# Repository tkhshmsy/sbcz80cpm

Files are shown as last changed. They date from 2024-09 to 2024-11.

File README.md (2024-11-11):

# sbcz80cpm
Single Board Computer with Z80 for CP/M

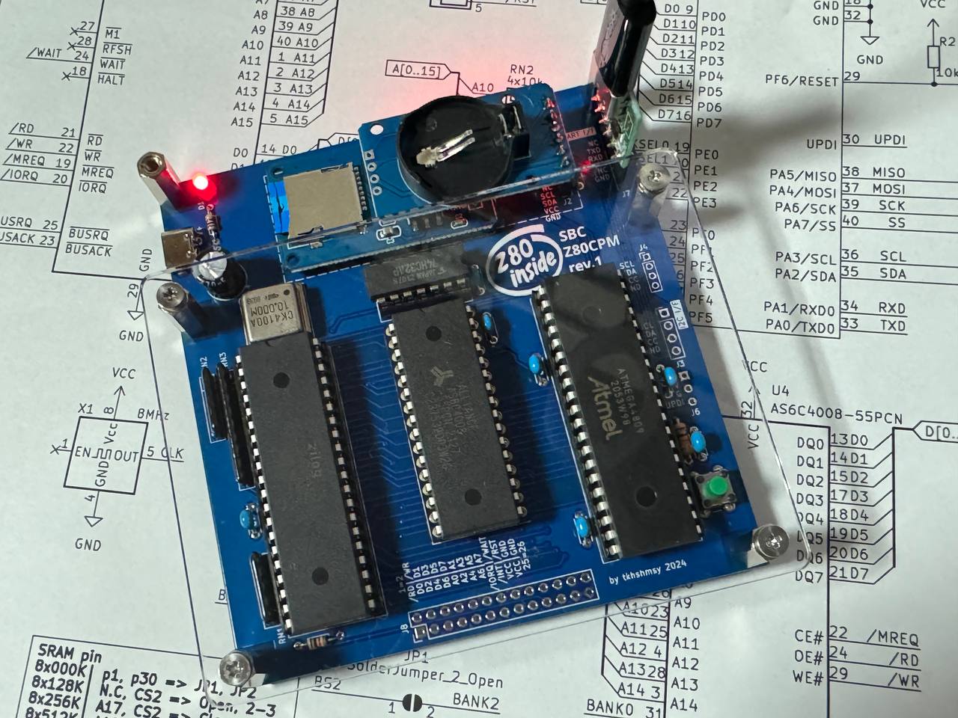
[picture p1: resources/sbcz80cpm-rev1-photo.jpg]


# Features
* Z80 cpu board for CP/M, without any ROM chips
  * supports 128KB to 512KB of SRAM, banked in 32KB
* ATMEGA4809 as I/O Engine sub system
  * Boot loader control
  * UART for console Input/Output
  * Floppy Disk Emulation with SD Card via SPI
  * RTC via I2C
  * other I2C devices

# PCB
## Schematics and Layout
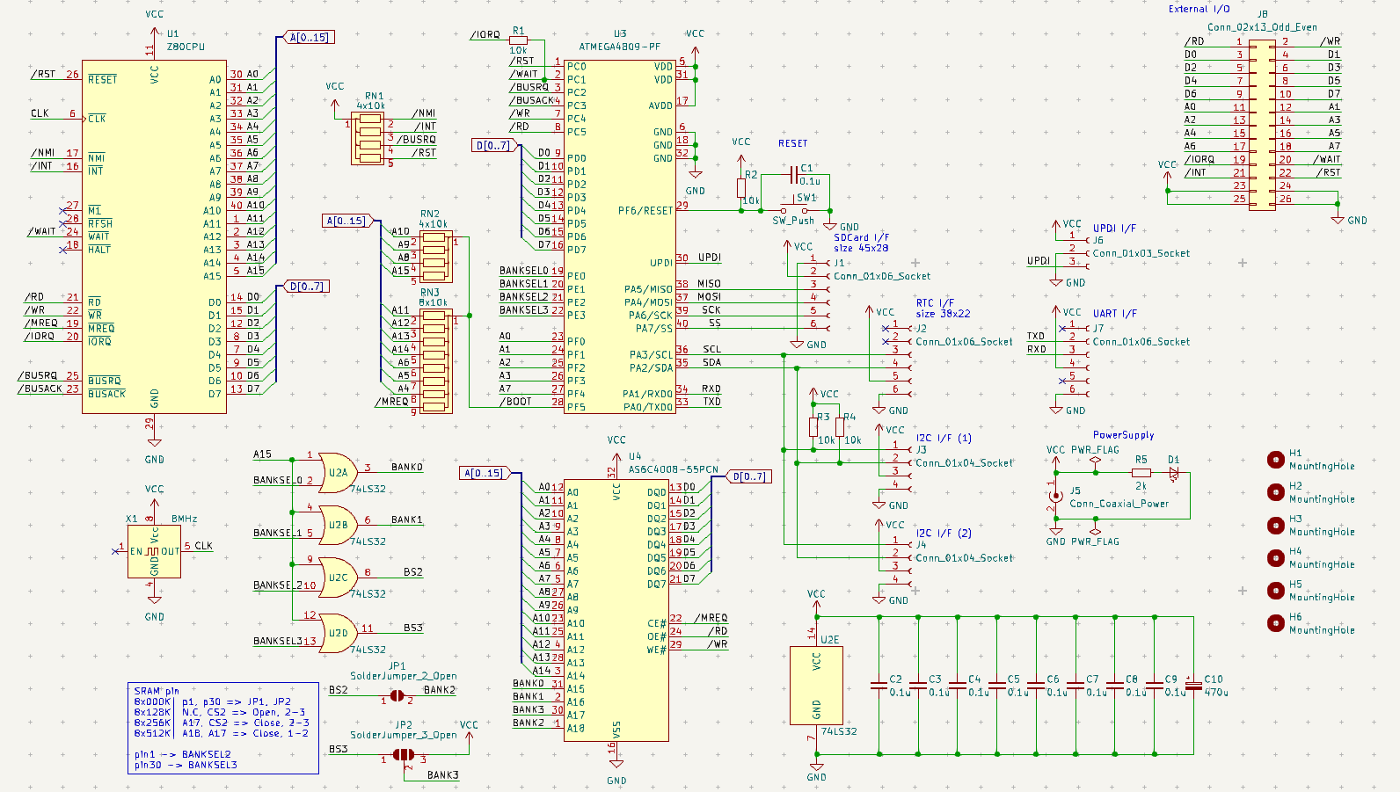
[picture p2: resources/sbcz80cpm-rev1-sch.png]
sch

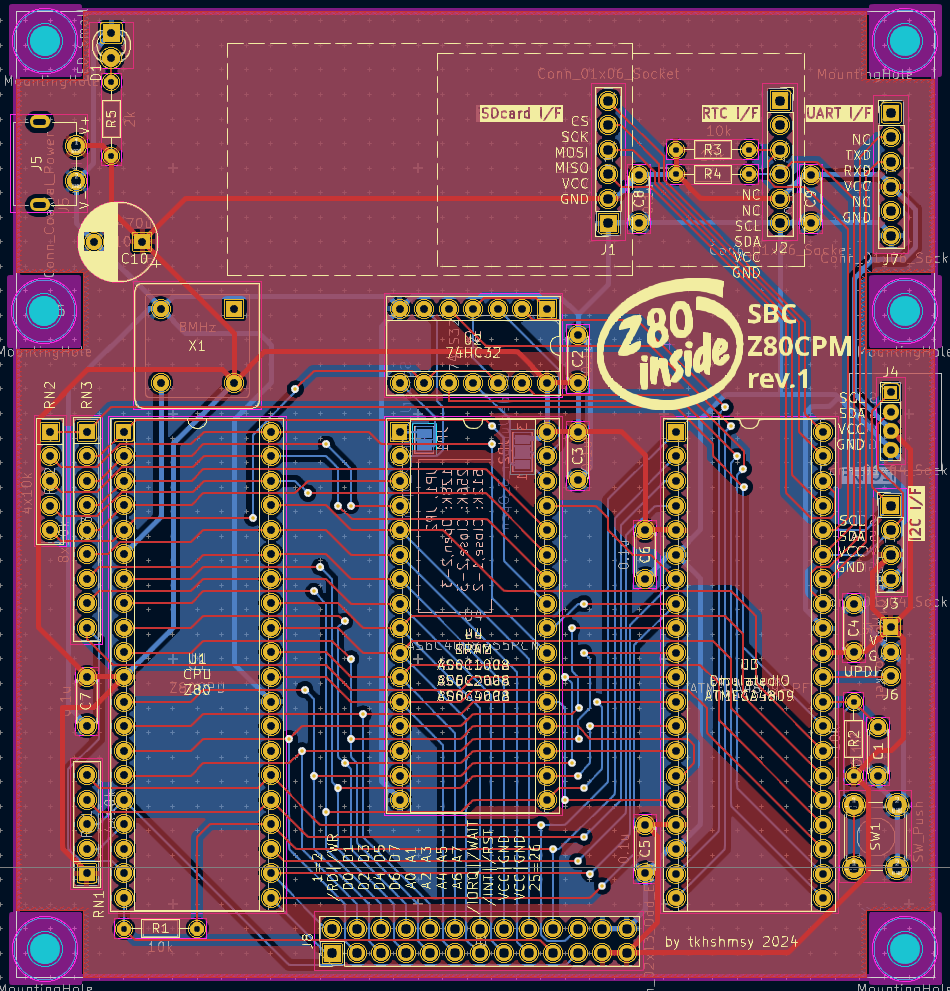
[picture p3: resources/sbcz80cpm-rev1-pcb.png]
pcb


## BOM
| Ref | Name | Qty | Description | Package | Link |
| --- | ---- | --- | --- | --- | ---- |
| U1 | Z80 | 1 | Z80 CPU | DIP40 | Zilog Z84C00*, NEC uPD780C |
| U2 | 74HC32 | 1 | Quad OR | DIP14 | [akizuki](https://akizukidenshi.com/catalog/g/g112877/)|
| U3 | ATMEGA4809 | 1 | ATMEGA4809 | PDIP40 | [akizuki](https://akizukidenshi.com/catalog/g/g116144/)|
| U4 | AS6C4008 | 1 | SRAM | DIP32 | [mouser](https://www.mouser.jp/ProductDetail/Alliance-Memory/AS6C4008-55PCN?qs=E5c5%252Bmu3i3%252BMOyro1Tlhzg%3D%3D)|
| X1 | 1-10MHz | 1 | Crystal OSC | DIP8 | [akizuki 8MHz](https://akizukidenshi.com/catalog/g/g117022/), [akizuki 10MHz](https://akizukidenshi.com/catalog/g/g117023/)|
| C1, C2, C3, C4, C5, C6, C7, C8, C9 | 0.1uF | 9 | | ||
| C10  | 470uF | 1 | | ||
| R1 | 1K-10K | 1 | for /WAIT control, 10K(-5MHz), 1K(8MHz-)| ||
| R2 | 10K | 1 | for pullup | ||
| R3, R4 | 10K | 2 | for I2C pullup | ||
| R5 | 1K | 1 | for LED | ||
| RN1 | 10Kx4 | 1 | for pullup | |[akizuki](https://akizukidenshi.com/catalog/g/g111909/)|
| RN2 | 10Kx4 | 1 | for IPL control | ||
| RN3 | 10Kx8 | 1 | for IPL control | |[akizuki](https://akizukidenshi.com/catalog/g/g111910/)|
| D1 | LED | 1 | 3mm | ||
| SW1 | Push Button | 1 | Reset SW| |[akizuki](https://akizukidenshi.com/catalog/g/g103647/)|
| J1, J2 | 1x6 Pin Socket | 2 | for SDCard, RTC | ||
| J3 | 1x4 Pin Socket | 1 | for I2C | pitch 2.54 ||
| J4 | 1x4 Pin Socket | 1 | for I2C | pitch 2.0 ||
| J5 | USB Type-C Power | 1 | for PowerSupply | |[akizuki](https://akizukidenshi.com/catalog/g/g116895/)|
| J6 | 1x3 Pin Socket | 1 | for UPDI | ||
| J7 | 1x6 Pin Header | 1 | for Serial comm | ||
| J8 | 2x13 Pin Header | 1 | for I/O Bus export | ||
| SDCard I/F | SD Card Module | 1 | | |[amazon.co.jp](https://www.amazon.co.jp/dp/B083DT3LQK)|
| RTC I/F | RTC Module | 1 | | |[amazon.co.jp](https://www.amazon.co.jp/dp/B081RJRB8N)|

## Memory Map

### System Memory
| Address | Size | Name | Note |
| ----- | ---- | ---- | ---- |
|0x0000 - 0x7FFF| 32KB | RAM | Banked memory selected with BANKSEL0-3 |
|0x8000 - 0xFFFF| 32KB | RAM | Fixed to "the tail of Banks" |

### SRAM Banks
* every 32KB, selected with BANKSEL0-3
  * Bank0 : 0x0000 - 0x7FFF
  * ...
* "the tail of Banks" which is mapped into 0x8000 - 0xFFFF on system
  * 128KB: 0x18000 - 0x1FFFF
  * 256KB: 0x28000 - 0x2FFFF
  * 512KB: 0x48000 - 0x4FFFF

# License
* MIT
  * contains follows
    * schematics and PCB
    * firmware `I/O Engine`
    * boot loaders and customized bios
  * the others are NOT included.

# Author
* [tkhshmsy@gmail.com](tkhshmsy@gmail.com)

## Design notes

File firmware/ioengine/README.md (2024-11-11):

# I/O Engine for sbcz80cpm

the I/O device for sbcz80cpm powered by [ATMEGA4809](https://www.microchip.com/en-us/product/atmega4809).

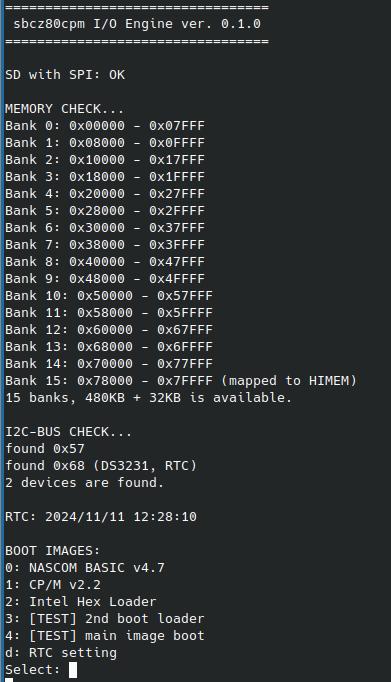
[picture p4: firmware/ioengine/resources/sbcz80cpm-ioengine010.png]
I/O Engine


## Features
* Boot control
  * provides IPL for no ROM / full RAM system
* I/O control, mostly for CP/M
  * Console I/O which is connected to host via UART
  * Disk I/O
  * RTC
  * communicate with I2C devices

## Requirements
* [platformio](https://platformio.org/)
  * cross development platform for embedded systems
* [pymcuprog](https://github.com/microchip-pic-avr-tools/pymcuprog)
  * serial to UPDI programmer for AVR

## Build
use platformio.
* modify `platformio.ini` if it needs

```bash
## only once, write the fuse to enable H/W RESET.
$ pio run -t fuses

## compile
$ pio run

## compile and upload
$ pio run -t upload
```

References,
* [PlatformIO Community/Hardware reset on AVR 4809](https://community.platformio.org/t/hardware-reset-on-avr-4809/24219)

## Design

### Connections
* for devices
  * UART
    * for host communication, 115200bps 8N1
  * I2C
    * RTC
    * other i2c devices
  * SPI
    * SD card, formatted VFAT/FAT32 
* for _Z80_
  * /WAIT, /IOREQ
  * /WR
  * /RD
  * AddressBus
  * DataBus
  * /MREQ

### Boot sequence and IPL
_sbcz80cpm_ is all RAM system, and has no ROM. Therefore, the IPL should be written into RAM by any way.
For this, at booting, _I/O Engine_ turns _Z80_ into bus master and writes IPL to the top of RAM.
However, as the _I/O Engine_(ATMEGA4809) has not enough I/O ports for address bus, the IPL needs to execute within a limited address space.

1. reset _Z80_
2. Loading _IPL_ (`/boot1st.bin`)
   1. assert /BUSREQ = 0
   2. wait until /BUSACK = 0 to enter BusMaster
   3. assert /BOOT = 0
      1. A15-8,A6-4 is 0
      2. /MREQ is 0 (SRAM is activated)
   4. assert A7 = 0
   5. using /WR, A0-3, write IPL from 0x0000 to 0x000F
   6. release /BOOT = 1
   7. release /BUSREQ = 1 to leave BusMaster
3. reset _Z80_, start _IPL_ from 0x0000
4. (_I/O Engine_ starts main loop)
5. _IPL_ (`/boot1st.bin`) is executed
   1. write 0x02 to I/O port 0x8F to prepare the binary of '2nd boot loader'
   2. read 256 times from I/O port 0x8F
      1. I/O Engine returns binary of _2nd boot loader_
   3. write each bytes from 0xFF00 to 0xFFFF.
   4. jump to 0xFF00
6. _2nd boot loader_ (e.g. `/boot2nd.bin`) is executed
   1. write 0x03 to I/O port 0x8F to prepare the binary of 'main image'
   2. read 32768 times from I/O port 0x8F
      1. I/O Engine returns binary of _main image_
   3. write each bytes from 0x0000 to 0x7FFF.
   4. jump to 0x0000

At here, the _IPL_ (boot1st.bin) has to be less than 16 bytes of code. Which is quite possible with the extra instructions of _Z80_.
Similarly, the _2nd Boot Loader_ has also to be less than 256 bytes of code, but for the _Z80_, 256 bytes is enough space to perform various operations.

### I/O sequence
The _I/O Engine_ needs to respond to IN/OUT instructions of _Z80_.
However, even though the _I/O Engine_ is running at 20MHz, it is still too slow to respond to the _Z80_ without WAIT.

So, it is solved this in the same way as other similar projects (e.g. [Z80MBC2](https://github.com/SuperFabius/Z80-MBC2), [Z80MBC3](https://github.com/eprive/Z80-MBC3)).

1. _I/O Engine_ waits until /WAIT = 0
   1. _Z80_ executes the instruction 'OUT'or 'IN', so assert /IOREQ = 0
   2. because /IOREQ connected to /WAIT with resistor, it turns /WAIT = 0
   3. IN/OUT command-cycle is 'T1, T2, TW, T3', _Z80_ waits until /WAIT =1.
      1. refer to [Z80 CPU User Manual](https://www.zilog.com/docs/z80/um0080.pdf) page 11
      2. in TW cycle, /RD,/WR, Address and Data is already asserted.
2. _I/O Engine_ reads /WR, /RD, Address and Data buses to execute it's API.
   1. /WR = 0 is asserted, it is a 'write' operation. _I/O Engine_ reads from Data bus.
   2. /RD = 0 is asserted, it is a 'read' operation. _I/O Engine_ changes Data bus to output, and outputs the data.
3. _I/O Engine_ releases bus,
   1. asserts /BUSREQ = 0
   2. asserts /WAIT = 1 as output port (at here, still /IOREQ = 0 yet)
      1. _Z80_ start to continues executing the T3 cycle and the next instruction.
      2. But because /BUSREQ = 0, _Z80_ waits at the head of T1 in M1 cycle of the next instruction.
         1.  refer to [Z80 CPU User Manual](https://www.zilog.com/docs/z80/um0080.pdf) page 12
         2. _Z80_ does not touch its buses yet and waits until /BUSACK = 0.
   3. release Data bus = High-Z as input port if the case that _I/O Engine_ was output any data.
   4. release /WAIT = High-Z as input port.
   5. asserts /BUSREQ = 1 to release all buses and wake up _Z80_.
4. _Z80_ continues to next cycle...

## Boot configuration
At booting, _I/O Engine_ read `/boot.cfg` from SD card.
`boot.cfg` is written in the TSV (Tab Separated Value) format and contains the following items.

* (1) the title of the setting
  * e.g. `CP/M 2.2`
* (2) the full-path of 2nd boot loader. 
  * Normally `/boot2nd.bin` is used, but a modified one is able to use.
  * e.g. `/cpm22/cpm22ipl.bin`
* (3) the full-path of main image
  * e.g. `/cpm22/bios.bin`
* (4) the prefix of the disk-image-files
  * e.g. `/cpm22`

The _prefix_ in the 4th item is used for creating _the image-filename_ of _the floppy-disk-emulation_ and is expanded as follows:
* `prefix` + `/disk` + \<disk no.\> + `.img`

## API as I/O device
Mainly for CP/M, the _I/O Engine_ provides API centered around FloppyDisk emulation.
It is placed under 8-bit addresses as a _Z80_'s I/O device.

About floppy-disk emulation, the default setting is _ibm-3740 format_ as follows:
* tracks per disk: 77 (allows 0-76)
* sectors per track: 26 (allows 0-25)
* sector length: 128 bytes

### for READ
| Address | Function | Description |
|---|---|---|
| 0x80 | UARTST | return the status of UART |
| 0x81 | UART | receive from UART |
| 0x82 | SELDSK | return the number of current disk |
| 0x83 | SETTRK | return the number of current track |
| 0x84 | SETSEC | return the number of current sector |
| 0x85 | DISKIO | read the current sector, must to read sector length continuously |
| 0x86 | ---- | Not Implemented yet |
| 0x87 | ---- | Not Implemented yet |
| 0x88 | ---- | Not Implemented yet |
| 0x89 | (UPTIME) | Not Implemented yet |
| 0x8A | RTC | read RTC |
| 0x8B | I2CTRANS | return the result of transmit() of i2c |
| 0x8C | I2CREQ | return the result of available() of i2c |
| 0x8D | I2CDATA  | read from i2c |
| 0x8E | BANK | return the current bank of SRAM |
| 0x8F | MISC | return the binary data for IPL |

#### UARTST
| bit | Description |
|-----|---|
| 7-2 | Not used |
| 1 | Tx condition, 1: able to transmit, 0: busy |
| 0 | Rx condition, 1: able to receive, 0: no char |

### for WRITE
| Address | Function | Description |
|---|---|---|
| 0x80 | UARTST | No response |
| 0x81 | UART | transmit to UART |
| 0x82 | SELDSK | select the current disk |
| 0x83 | SETTRK | set the current track |
| 0x84 | SETSEC | set the current sector |
| 0x85 | DISKIO | write the current sector, must to write sector length continuously |
| 0x86 | ---- | Not Implemented yet |
| 0x87 | ---- | Not Implemented yet |
| 0x88 | ---- | Not Implemented yet |
| 0x89 | (UPTIME) | Not Implemented yet |
| 0x8A | RTC | write RTC |
| 0x8B | I2CTRANS | send transmit() to i2c |
| 0x8C | I2CREQ | send request() to i2c |
| 0x8D | I2CDATA  | write into i2c |
| 0x8E | BANK | set the current bank of SRAM |
| 0x8F | MISC | input |

#### MISC input
| value | description |
|---|---|
| 0x00  | set the dummy data 0x00 |
| 0x01  | set the binary of fixed _1st boot loader_ |
| 0x02  | set the binary of selected _2nd boot loader_ |
| 0x03  | set the binary of selected _main image_ |
| 0xFF  | reset _Z80_ |

## References
* Zilog
  * [Z80 CPU User Manual](https://www.zilog.com/docs/z80/um0080.pdf)
* Microchip ATMEGA4809
  * [ATMEGA4809](https://www.microchip.com/en-us/product/atmega4809)
  * [Datasheet](https://ww1.microchip.com/downloads/aemDocuments/documents/MCU08/ProductDocuments/DataSheets/ATmega4808-09-DataSheet-DS40002173C.pdf)
* Other Projects
  * [Z80MBC2](https://github.com/SuperFabius/Z80-MBC2)
  * [Z80MBC3](https://github.com/eprive/Z80-MBC3)

## License
* MIT

## Author
* [tkhshmsy@gmail.com](tkhshmsy@gmail.com)

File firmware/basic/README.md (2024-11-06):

# NASCOM BASIC v4.7b

forked from [Microsoft BASIC 4.7b](http://searle.x10host.com/z80/sbc_NascomBasic.zip) of Grant Searle's project.  

* BASIC interpreter for Z80
* BIOS.ASM is customized for sbcz80cpm
  * use UART for console Input/Output

```
Initializing sbcz80cpm...

Memory top? 
Z80 BASIC Ver 4.7b
Copyright (C) 1978 by Microsoft
56958 Bytes free
Ok

10 FOR I=0 TO 10
20 PRINT "Hello world!"
30 NEXT
run
Hello world!
Hello world!
Hello world!
Hello world!
Hello world!
Hello world!
Hello world!
Hello world!
Hello world!
Hello world!
Hello world!
Ok
```

## Requirements
* 'zasm' assembler
  * [zasm](https://k1.spdns.de/Develop/Projects/zasm/Distributions/)

## Build
* download 'basic.asm' from Grant's HomePage.
* execute 'make' command to get 'msbasic.bin'
```bash
/sbcz80cpm/firmware/basic$ ls
Makefile  README.md  basic.asm  init.asm

/sbcz80cpm/firmware/basic$ make
zasm -wuyb init.asm -o init.obj
assembled file: init.asm
    107 lines, 2 passes, 0.0015 sec.
    no errors

zasm -wuyb basic.asm -o basic.obj
assembled file: basic.asm
    4341 lines, 2 passes, 0.0261 sec.
    no errors

cat init.obj basic.obj > msbasic.bin

/sbcz80cpm/firmware/basic$ ls
Makefile  README.md  basic.asm  basic.lst  basic.obj  init.asm  init.lst  init.obj  msbasic.bin
```

### Setup

1. Copy `msbasic.bin` into `/basic` directory in SDcard.
2. Set up `/boot.cfg`
   1. set `/boot2nd.bin` as 2nd boot loader
      1. the general 2nd boot loader loads too many bytes, but it's safe.
   2. set `/basic/msbasic.bin` as main image
   3. set `/basic` as prefix to access disk images
      1. this is not neccessary, but recommended to avoid conflicts.
3. then, restart sbcz80cpm, and select above setting.

## References
* [Grant's homebuilt electronics](http://searle.x10host.com/)
  * [Grant's 7-chip Z80 computer](http://searle.x10host.com/z80/SimpleZ80.html)

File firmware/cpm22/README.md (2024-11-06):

# CP/M ver 2.2

62K CP/M ver 2.2 for sbcz80cpm

## Requirements
* 'zasm' assembler
  * [zasm](https://k1.spdns.de/Develop/Projects/zasm/Distributions/)
* 'cpmtools'
  * [Michael Haardt's cpmtools Main Page](http://www.moria.de/~michael/cpmtools/)
  * On Ubuntu, use `sudo apt install cpmtools`

## How to build
### BIOS and IPL
* bios.asm (bios.bin)
  * 62K CP/M ver 2.2 BIOS for sbcz80cpm
    * allocated at 0xF200
  * BOOT and WBOOT as CP/M API, loads system binary from 'disk0.img'
* cpm22ipl.asm (cpm22ipl.bin)
  * 2nd boot loader for sbcz80cpm
  * loads BIOS into 0xF200 and jump to 0xF200

```bash
/sbcz80cpm/firmware/cpm22$ ls
Makefile  README.md  bios.asm  cpm22ipl.asm

/sbcz80cpm/firmware/cpm22$ make
rm -f bios.bin cpm22ipl.bin *.lst *.hex
zasm -wuyb bios.asm -o bios.bin
assembled file: bios.asm
    368 lines, 2 passes, 0.0029 sec.
    no errors

zasm -wuyb cpm22ipl.asm -o cpm22ipl.bin
assembled file: cpm22ipl.asm
    57 lines, 2 passes, 0.0010 sec.
    no errors

/sbcz80cpm/firmware/cpm22$ ls
Makefile  README.md  bios.asm  bios.bin  bios.lst  cpm22ipl.asm  cpm22ipl.bin  cpm22ipl.lst
```
## How to set up system

### Get the system binary

1. Download OPERATING SYSTEMS binary from '[Unofficial CP/M Web site](http://www.cpm.z80.de/)'.
   * [CP/M 2.2 BINARY](http://www.cpm.z80.de/download/cpm22-b.zip)
2. Unpack to get the binary file 'CPM.SYS'.
   * 'CPM.SYS' includes CCP, BDOS, BIOS for 62K CP/M on Xerox1800 system.
3. Not using the BIOS for Xerox1800, so remove it and make CCP and BDOS binary.
   * `dd if=CPM.SYS of=ccpbdos.bin bs=128 count=44`
4. Make the system disk image at following step.

### Make the disk images

`bios.asm` is the 62K CP/M ver 2.2 BIOS for sbcz80cpm,
* supports _ibm-3740_ formatted disk image.
* supports 4 disks mounted.
  * `disk0.img`: system disk, must to install CCP and BDOS into boot track.
  * `disk1.img`: user disk (no needs the boot track)
  * `disk2.img`: user disk
  * `disk3.img`: user disk

> [!NOTE]
> ibm-3740 formatted disk image.
> * 77 tracks per disk
> * 26 sectors per track
> * 128 bytes per sector
> * 2 reserved tracks for system
> * skew factor is 6
> * Total: 256,256 bytes per disk

```bash
## System disk
### make empty disk image file (size = 128 * 26 * 77)
$ dd if=/dev/zero of=disk0.img bs=3328 count=77
### mkfs.cpm with ibm-3740 format and install the system binary into boot track
$ mkfs.cpm -f ibm-3740 -b ccpbdos.bin -L system disk0.img

## User disk (e.g. disk1.img)
$ dd if=/dev/zero of=disk1.img bs=3328 count=77
$ mkfs.cpm -f ibm-3740 disk1.img
```

To boot up CP/M, no files are needed but only the BIOS and the system binary in boot track.

### Control disk images
Using any other commands and files on CP/M, use cpmtools to deploy into disk images.

```bash
## list files in disk0.img
$ cpmls -f ibm-3740 disk0.img
## copy local file 'file.bin' into disk0.img (user 0)
$ cpmcp -f ibm-3740 disk0.img ./file.bin 0:
## copy file '0:file.bin' from disk0.img to local
$ cpmcp -f ibm-3740 disk0.img 0:file.bin ./
## remove '0:file.bin' from disk0.img
$ cpmrm -f ibm-3740 disk0.img 0:file.bin
```

> [!NOTE]
> _ibm-3740_ is the default format of cpmtools.
> so, `-f ibm-3740` option is able to be omitted.

### Setup sbcz80cpm

1. Copy `bios.bin` and `cpm22ipl.bin` into `/cpm22` directory in SDcard.
2. Copy disk images into `/cpm22` directory in SDcard.
3. Set up `/boot.cfg`
   1. set `/cpm22/cpm22ipl.bin` as 2nd boot loader
   2. set `/cpm22/bios.bin` as main image
   3. set `/cpm22` as prefix to access disk images
4. then, restart sbcz80cpm, and select above setting.

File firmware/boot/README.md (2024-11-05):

# Boot loaders for sbcz80cpm

## Contents
* Makefile
  * Makefile for all
* README.md
  * this document
* boot1st.asm
  * IPL for sbcz80cpm
    * load selected '2nd boot loader' into 0xff00, and jump to
* boot2nd.asm
  * general 2nd boot loader
    * load 32KB into 0x0000
* bootihex.asm
  * intel hex loader
    * load intel-hex formatted file
      * recommended to use 'slowtransfer.sh' because of no flow control.
    * after loaded, input 'StartAddress' to jump to
* slowtransfer.sh
  * script for 'slow' transfer
    * usage: `./slowtransfer.sh <device> <filename>`
    * send each bytes with interval
* test2nd.asm
  * test code of 2nd boot loader
    * output message and HALT
* testimg.asm
  * test code of main image
    * output message and HALT

## Requirements
* 'zasm' assembler
  * [zasm](https://k1.spdns.de/Develop/Projects/zasm/Distributions/)

## Build
* execute 'make' command

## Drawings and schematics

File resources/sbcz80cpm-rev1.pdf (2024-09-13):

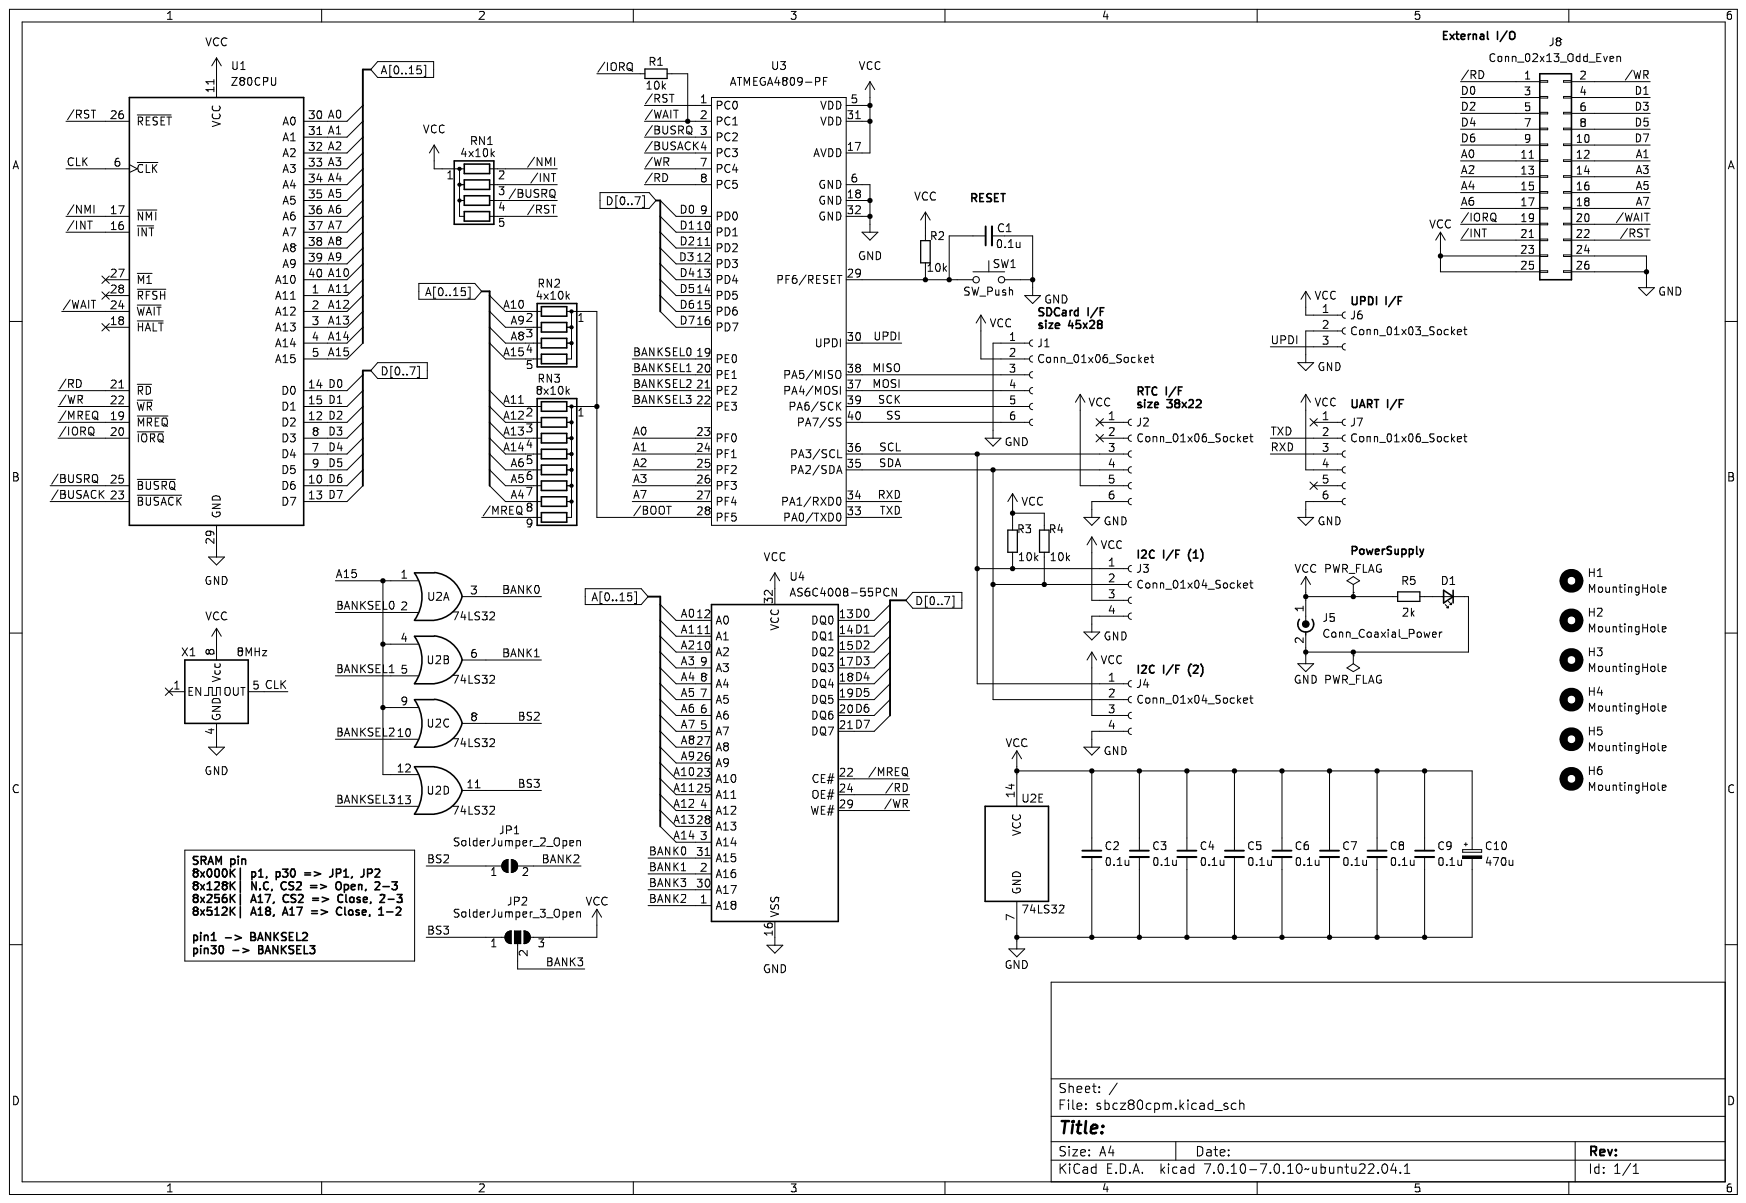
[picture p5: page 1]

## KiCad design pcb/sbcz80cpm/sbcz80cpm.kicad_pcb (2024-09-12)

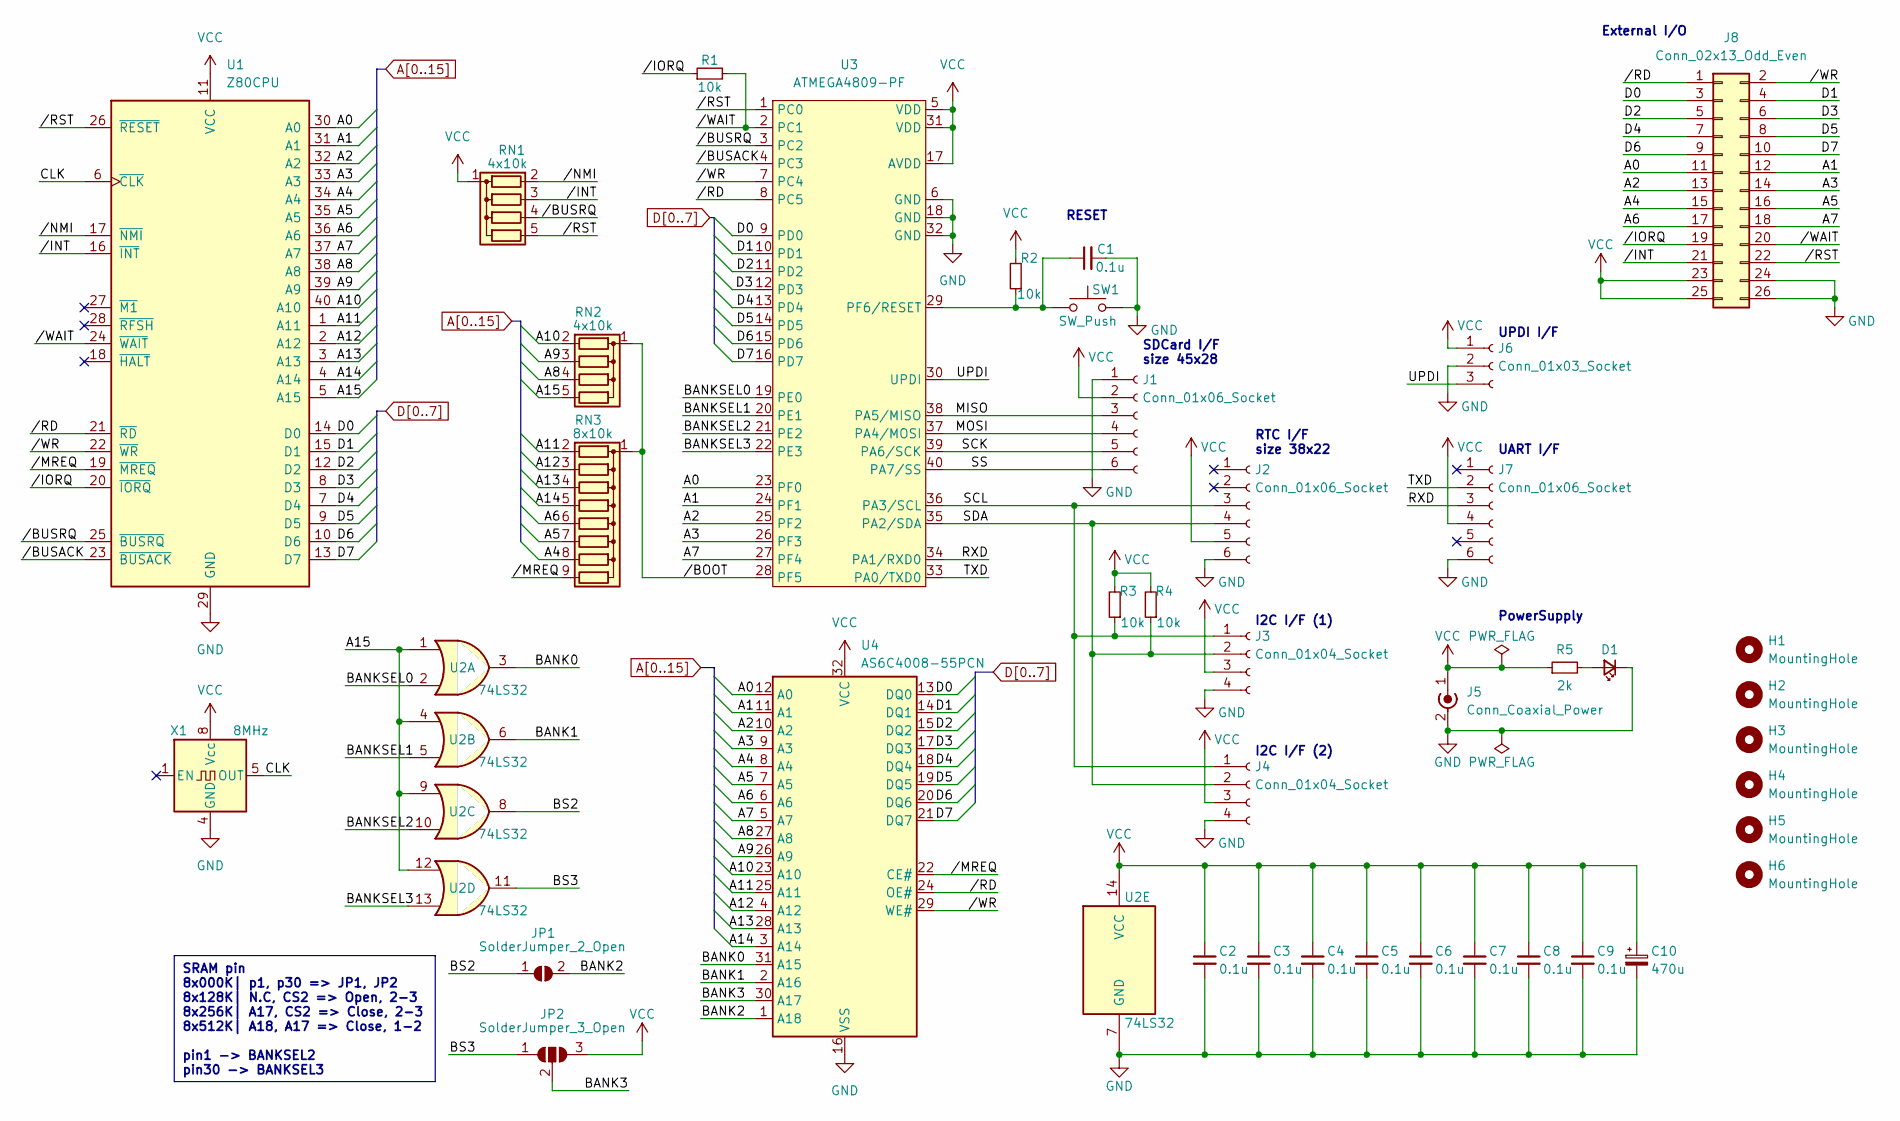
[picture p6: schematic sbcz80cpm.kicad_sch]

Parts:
C1, C2, C3, C4, C5, C6, C7, C8, C9: 0.1u; C_Disc_D4.3mm_W1.9mm_P5.00mm
C10: 470u; CP_Radial_D8.0mm_P5.00mm
D1: LED_Small; LED_D3.0mm
H1, H2, H3, H4, H5, H6: MountingHole; MountingHole_3.2mm_M3
J1, J2: Conn_01x06_Socket; PinSocket_1x06_P2.54mm_Vertical
J3: Conn_01x04_Socket; PinHeader_1x04_P2.54mm_Vertical
J4: Conn_01x04_Socket; PinHeader_1x04_P2.00mm_Vertical
J5: Conn_Coaxial_Power; A295-CTRPB-1
J6: Conn_01x03_Socket; UPDIconn
J7: Conn_01x06_Socket; PinHeader_1x06_P2.54mm_Vertical
J8: Conn_02x13_Odd_Even; PinHeader_2x13_P2.54mm_Vertical
JP1: SolderJumper_2_Open; SolderJumper-2_P1.3mm_Open_Pad1.0x1.5mm
JP2: SolderJumper_3_Open; SolderJumper-3_P1.3mm_Open_Pad1.0x1.5mm_NumberLabels
R1, R2, R3, R4: 10k; R_Axial_DIN0204_L3.6mm_D1.6mm_P7.62mm_Horizontal
R5: 2k; R_Axial_DIN0204_L3.6mm_D1.6mm_P7.62mm_Horizontal
RN1, RN2: 4x10k; R_Array_SIP5
RN3: 8x10k; R_Array_SIP9
SW1: SW_Push; SW_PUSH_6mm
U1: Z80CPU; DIP-40_W15.24mm_Socket
U2: 74LS32; DIP-14_W7.62mm_Socket
U3: ATMEGA4809-PF; DIP-40_W15.24mm_Socket
U4: AS6C4008-55PCN; DIP-32_W15.24mm_Socket
X1: 8MHz; Oscillator_DIP-8

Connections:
/BANK0: U2.3, U4.31 (A15)
/BANK1: U2.6, U4.2 (A16)
/BANK2: JP1.2 (B), U4.1 (A18)
/BANK3: JP2.2 (C), U4.30 (A17)
/BANKSEL0: U2.2, U3.19 (PE0)
/BANKSEL1: U2.5, U3.20 (PE1)
/BANKSEL2: U2.10, U3.21 (PE2)
/BANKSEL3: U2.13, U3.22 (PE3)
/BS2: JP1.1 (A), U2.8
/BS3: JP2.1 (A), U2.11
/CLK: U1.6 (~CLK), X1.5 (OUT)
/MISO: J1.3, U3.38 (PA5/MISO)
/MOSI: J1.4, U3.37 (PA4/MOSI)
/RXD: J7.3, U3.34 (PA1/RXD0)
/SCK: J1.5, U3.39 (PA6/SCK)
/SCL: J2.3, J3.1, J4.1, R3.1, U3.36 (PA3/SCL)
/SDA: J2.4, J3.2, J4.2, R4.1, U3.35 (PA2/SDA)
/SS: J1.6, U3.40 (PA7/SS)
/TXD: J7.2, U3.33 (PA0/TXD0)
/UPDI: J6.3, U3.30 (UPDI)
//BOOT: RN2.1 (common), RN3.1 (common), U3.28 (PF5)
//BUSACK: U1.23 (~BUSACK), U3.4 (PC3)
//BUSRQ: RN1.4 (R3), U1.25 (~BUSRQ), U3.3 (PC2)
//INT: J8.21, RN1.3 (R2), U1.16 (~INT)
//IORQ: J8.19, R1.1, U1.20 (~IORQ)
//MREQ: RN3.9 (R8), U1.19 (~MREQ), U4.22 (CE#)
//NMI: RN1.2 (R1), U1.17 (~NMI)
//RD: J8.1, U1.21 (~RD), U3.8 (PC5), U4.24 (OE#)
//RST: J8.22, RN1.5 (R4), U1.26 (~RESET), U3.1 (PC0)
//WAIT: J8.20, R1.2, U1.24 (~WAIT), U3.2 (PC1)
//WR: J8.2, U1.22 (~WR), U3.7 (PC4), U4.29 (WE#)
A0: J8.11, U1.30 (A0), U3.23 (PF0), U4.12 (A0)
A1: J8.12, U1.31 (A1), U3.24 (PF1), U4.11 (A1)
A2: J8.13, U1.32 (A2), U3.25 (PF2), U4.10 (A2)
A3: J8.14, U1.33 (A3), U3.26 (PF3), U4.9 (A3)
A4: J8.15, RN3.8 (R7), U1.34 (A4), U4.8 (A4)
A5: J8.16, RN3.7 (R6), U1.35 (A5), U4.7 (A5)
A6: J8.17, RN3.6 (R5), U1.36 (A6), U4.6 (A6)
A7: J8.18, U1.37 (A7), U3.27 (PF4), U4.5 (A7)
A8: RN2.4 (R3), U1.38 (A8), U4.27 (A8)
A9: RN2.3 (R2), U1.39 (A9), U4.26 (A9)
A10: RN2.2 (R1), U1.40 (A10), U4.23 (A10)
A11: RN3.2 (R1), U1.1 (A11), U4.25 (A11)
A12: RN3.3 (R2), U1.2 (A12), U4.4 (A12)
A13: RN3.4 (R3), U1.3 (A13), U4.28 (A13)
A14: RN3.5 (R4), U1.4 (A14), U4.3 (A14)
A15: RN2.5 (R4), U1.5 (A15), U2.1, U2.4, U2.9, U2.12
D0: J8.3, U1.14 (D0), U3.9 (PD0), U4.13 (DQ0)
D1: J8.4, U1.15 (D1), U3.10 (PD1), U4.14 (DQ1)
D2: J8.5, U1.12 (D2), U3.11 (PD2), U4.15 (DQ2)
D3: J8.6, U1.8 (D3), U3.12 (PD3), U4.17 (DQ3)
D4: J8.7, U1.7 (D4), U3.13 (PD4), U4.18 (DQ4)
D5: J8.8, U1.9 (D5), U3.14 (PD5), U4.19 (DQ5)
D6: J8.9, U1.10 (D6), U3.15 (PD6), U4.20 (DQ6)
D7: J8.10, U1.13 (D7), U3.16 (PD7), U4.21 (DQ7)
GND: C1.2, C2.2, C3.2, C4.2, C5.2, C6.2, C7.2, C8.2, C9.2, C10.2, D1.1 (K), J1.1, J2.6, J3.4, J4.4, J5.2 (Ext), J6.2, J7.6, J8.24, J8.26, SW1.2, U1.29 (GND), U2.7 (GND), U3.6 (GND), U3.18 (GND), U3.32 (GND), U4.16 (VSS), X1.4 (GND)
unnamed: D1.2 (A), R5.2
unnamed: C1.1, R2.1, SW1.1, U3.29 (PF6/RESET)
VCC: C2.1, C3.1, C4.1, C5.1, C6.1, C7.1, C8.1, C9.1, C10.1, J1.2, J2.5, J3.3, J4.3, J5.1 (In), J6.1, J7.4, J8.23, J8.25, JP2.3 (B), R2.2, R3.2, R4.2, R5.1, RN1.1 (common), U1.11 (VCC), U2.14 (VCC), U3.5 (VDD), U3.17 (AVDD), U3.31 (VDD), U4.32 (VCC), X1.8 (Vcc)

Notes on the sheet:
SRAM pin 8x000K| p1, p30 => JP1, JP2 8x128K| N.C, CS2 => Open, 2-3 8x256K| A17, CS2 => Close, 2-3 8x512K| A18, A17 => Close, 1-2 pin1 -> BANKSEL2 pin30 -> BANKSEL3
UART I/F
External I/O
PowerSupply
UPDI I/F
I2C I/F (1)
RESET
RTC I/F size 38x22
I2C I/F (2)
SDCard I/F size 45x28

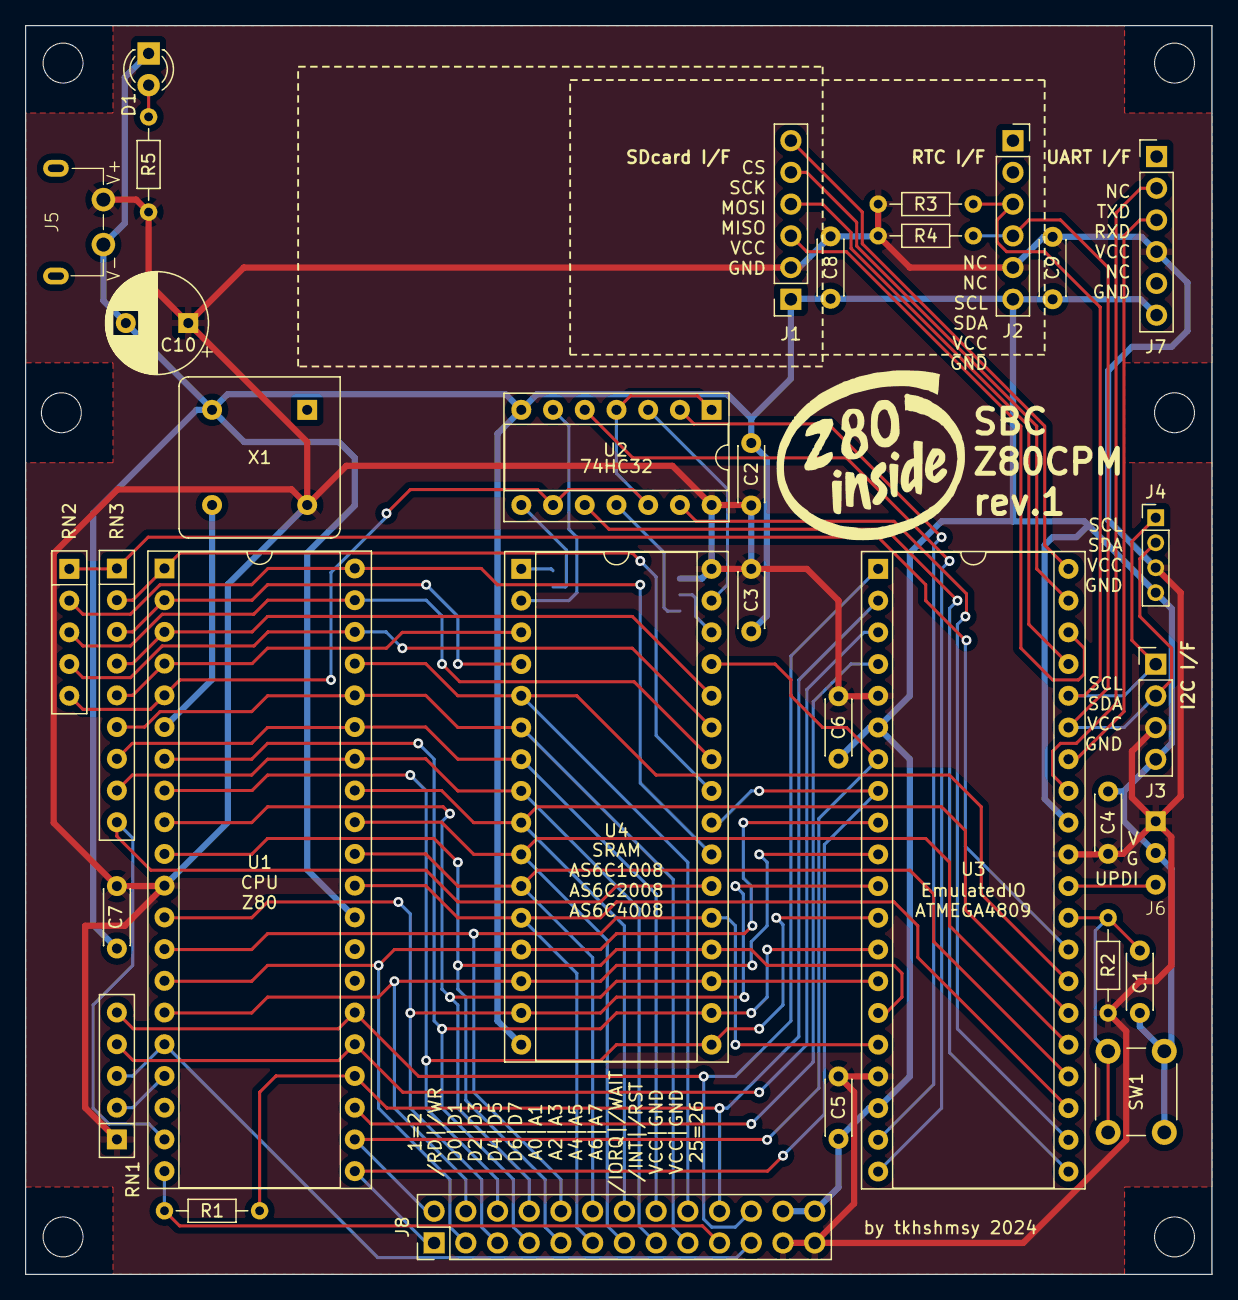
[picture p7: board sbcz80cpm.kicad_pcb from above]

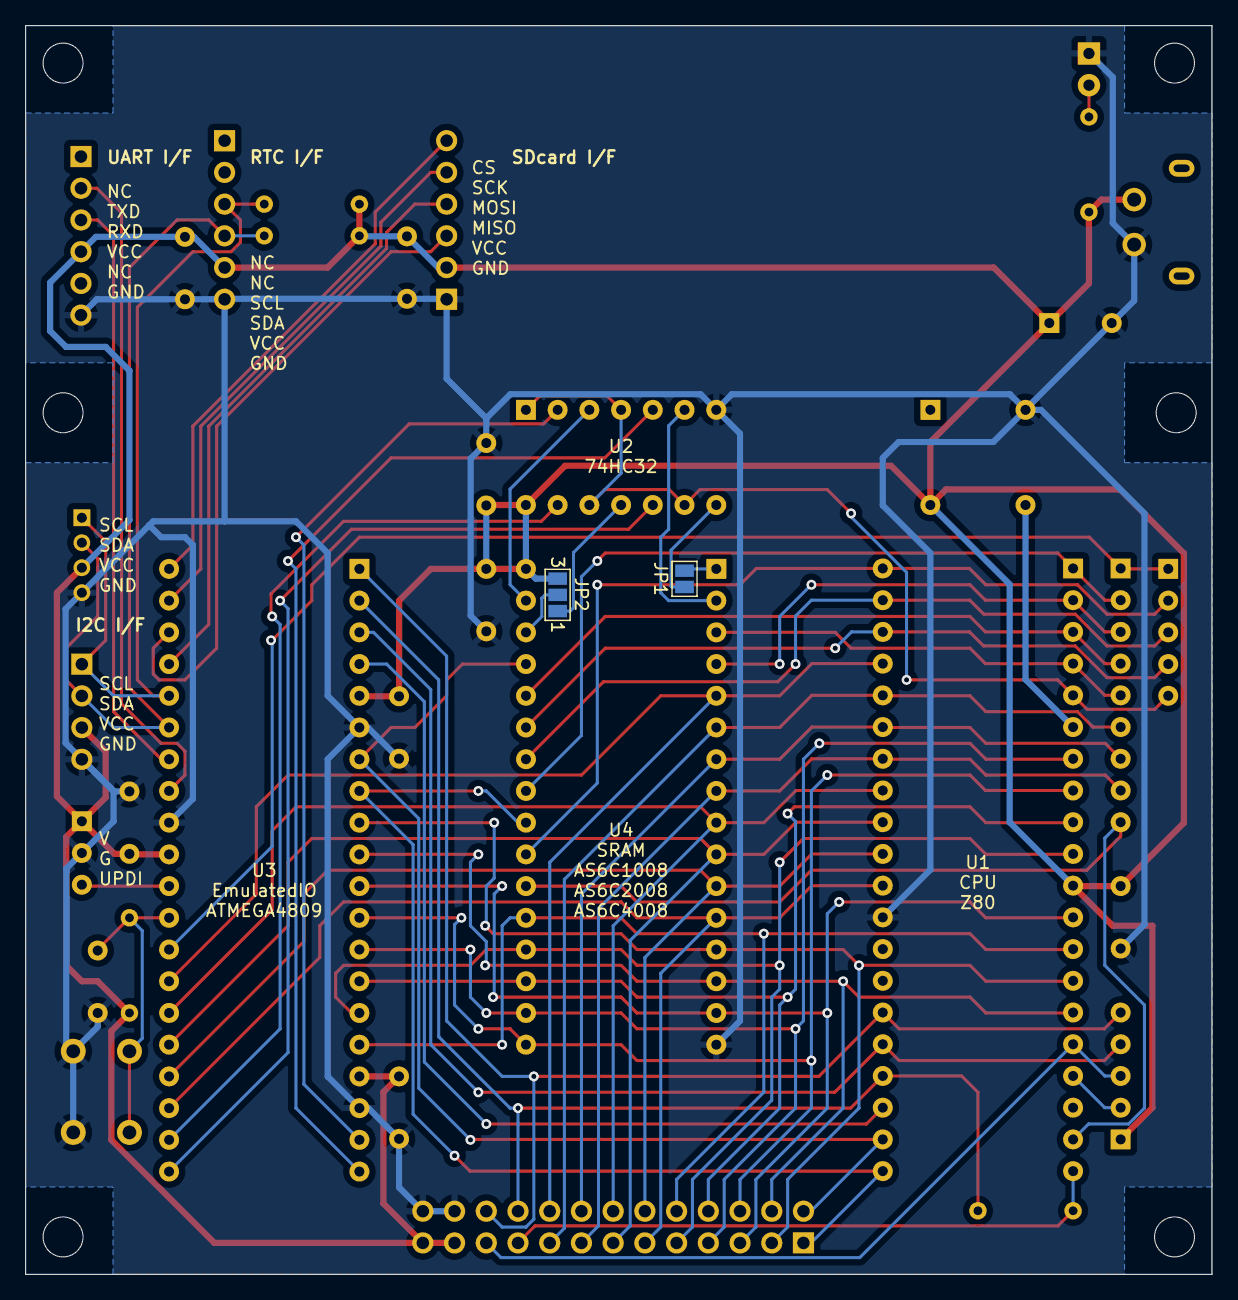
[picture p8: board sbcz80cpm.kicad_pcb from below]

Board: 2 copper layers, 95.0 x 100.0 mm, 41 parts (2 on the bottom side), 59 nets.

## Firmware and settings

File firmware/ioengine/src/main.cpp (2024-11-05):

#include <Arduino.h>
#include "ioengine.h"
#include "z80cpu.h"
#include "storage.h"
#include "i2cdevice.h"

Z80CPU *z80 = nullptr;
Storage *storage = nullptr;
I2CDevice *i2cDevice = nullptr;
uint8_t max_bank = 0;
uint8_t boot_mode = 0;
uint64_t boot_image_size = 0;
uint64_t boot_image_offset = 0;
uint8_t boot_uptime_buffer[2];
uint8_t boot_uptime_offset = 0;
uint8_t rtc_buffer[6];
uint8_t rtc_offset = 0;
uint8_t i2c_result = 0;
bool debug = false;

void io_write(uint8_t address, uint8_t data);
uint8_t io_read(uint8_t address)
{
    if (debug) {
        Serial.println("[IOE] io_read: addr=" + String(address, HEX));
    }
    uint8_t result = 0x00;
    if (address == 0x80) {
        // UART status
        result = Serial.available() ? 0x01 : 0x00;
        result |= Serial.availableForWrite() ? 0x02 : 0x00;
    } else if (address == 0x81) {
        // UART receive
        while(Serial.available() <= 0) {
            delay(1);
        }
        result = Serial.read();
    } else if (address == 0x82) {
        // CPM/disk
        result = storage->disk();
    } else if (address == 0x83) {
        // CPM/track
        result = storage->track();
    } else if (address == 0x84) {
        // CPM/sector
        result = storage->sector();
    } else if (address == 0x85) {
        // CP/M read data (multi bytes)
        bool ok = false;
        result = storage->readByte(&ok);
        if (!ok) {
            Serial.println("[IOE] read error");
        }
    } else if (address == 0x86) {
        // not implemented yet
    } else if (address == 0x87) {
        // not implemented yet
    } else if (address == 0x88) {
        // not implemented yet
    } else if (address == 0x89) {
        // not implemented yet
    } else if (address == 0x8a) {
        // CP/M read rtc (6 bytes)
        if (rtc_offset == 0) {
            i2cDevice->readRTC(rtc_buffer);
        }
        result = rtc_buffer[rtc_offset++];
        if (rtc_offset >= 6) {
            rtc_offset = 0;
        }
    } else if (address == 0x8b) {
        // I2C/start/end transmit result
        result = i2c_result;
    } else if (address == 0x8c) {
        // I2C/available
        result = i2cDevice->available();
    } else if (address == 0x8d) {
        // I2C/read data
        result = i2cDevice->read();
    } else if (address == 0x8e) {
        // current bank
        result = z80->bank();
    } else if (address == 0x8f) {
        // misc output
        if (boot_mode != 0) {
            bool ok = false;
            result = storage->readByteToBoot(&ok);
            if (ok) {
                boot_image_offset++;
                if (boot_image_offset >= boot_image_size) {
                    Serial.println(" OK");
                    io_write(0x8f, 0x00);
                }
            }
        }
    }
    if (debug) {
        Serial.println("[IOE] io_read: data=" + String(result, HEX));
    }
    return result;
}

void io_write(uint8_t address, uint8_t data)
{
    if (debug) {
        Serial.println("[IOE] io_write: addr=" + String(address, HEX) + " data=" + String(data, HEX));
    }
    if (address == 0x80) {
        // not implemented yet
    } else if (address == 0x81) {
        // UART transmit
        Serial.write(data);
    } else if (address == 0x82) {
        // CPM/disk
        storage->setDisk(data);
    } else if (address == 0x83) {
        // CPM/track
        storage->setTrack(data);
    } else if (address == 0x84) {
        // CPM/sector
        storage->setSector(data);
    } else if (address == 0x85) {
        // CP/M write data (multi bytes)
        int s = storage->writeByte(data);
        if (s <= 0) {
            Serial.println("[IOE] write error");
        }
    } else if (address == 0x86) {
        // not implemented yet
    } else if (address == 0x87) {
        // not implemented yet
    } else if (address == 0x88) {
        // not implemented yet
    } else if (address == 0x89) {
        // not implemented yet
    } else if (address == 0x8a) {
        // CP/M write rtc (6 bytes)
        rtc_buffer[rtc_offset++] = data;
        if (rtc_offset >= 6) {
            i2cDevice->writeRTC(rtc_buffer);
            rtc_offset = 0;
        }
    } else if (address == 0x8b) {
        // I2C/transmit
        i2c_result = i2cDevice->transmit(data);
    } else if (address == 0x8c) {
        // I2C/request
        i2cDevice->request(data);
    } else if (address == 0x8d) {
        // I2C/write data
        i2cDevice->write(data);
    } else if (address == 0x8e) {
        // set bank
        z80->setBank(data);
    } else if (address == 0x8f) {
        // misc input
        if (data == 0x00) {
            boot_mode = 0;
            boot_image_offset = 0;
            boot_image_size = 0;
        } else if (data == 0x01) {
            boot_mode = 1;
            boot_image_offset = 0;
            boot_image_size = storage->openBoot1st();
            Serial.print("1stStage(" + String((long)boot_image_size) + "bytes): ");
        } else if (data == 0x02) {
            boot_mode = 2;
            boot_image_offset = 0;
            boot_image_size = storage->openBoot2nd();
            Serial.print("2ndStage(" + String((long)boot_image_size) + "bytes): ");
        } else if (data == 0x03) {
            boot_mode = 3;
            boot_image_offset = 0;
            boot_image_size = storage->openBootImage();
            Serial.print("bootImage(" + String((long)boot_image_size) + "bytes): ");
        } else if (data == 0xff) {
            Serial.println("[IOE] CPU Reset...");
            z80->reset();
        }
    }
}

void boot1stStage()
{
    z80->blockUntilBusMaster(true);
    z80->assertBootMode();

    io_write(0x8f, 0x01);
    for (uint8_t addr = 0; addr < boot_image_size; addr++) {
        z80->writeBusMaster(addr, io_read(0x8f));
    }

    z80->releaseBootMode();
    z80->releaseBusMaster();
    z80->reset();
}

void boot_message()
{
    Serial.println("\n\n");
    Serial.println("=================================");
    Serial.println(" sbcz80cpm I/O Engine ver. " EIO_VERSION);
    Serial.println("=================================");
    Serial.println();
}

void setup()
{
    Serial.begin(115200, SERIAL_8N1);
    boot_message();

    storage = new Storage();
    i2cDevice = new I2CDevice();
    z80 = new Z80CPU();

    max_bank = z80->memoryCheck();
    z80->assertReset();

    i2cDevice->search();
    i2cDevice->showRTC();
    Serial.println();

    storage->showMenu();
    i2cDevice->showMenu();
    while (1) {
        Serial.print("Select: ");
        while (Serial.available() <= 0) {
            delay(100);
        };
        char c = Serial.read();
        if ('0' <= c && c <= '9') {
            Serial.write(c);
            uint8_t index = c - '0';
            if (storage->selectMenu(index)){
                break;
            }
        } else if ('a' <= c && c <= 'z') {
            Serial.write(c);
            if (i2cDevice->selectMenu(c)) {
                break;
            }
        }
        Serial.println();
    }
    Serial.println();
    z80->releaseReset();

    boot1stStage();
}

void loop()
{
    z80->blockUntilWait();
    if (debug) {
        Serial.println(String("[IOE]")
                    + " addr=" + String(z80->address(), HEX)
                    + " data=" + String(z80->data(), HEX)
                    + " wr=" + String(z80->wr())
                    + " rd=" + String(z80->rd()));
    }
    if ((z80->address() & 0x80) != 0x00) {
        if (z80->rd()) {
            uint8_t data = io_read(z80->address());
            z80->assertDataBus(data);
        } else if (z80->wr()) {
            io_write(z80->address(), z80->data());
        } else {
            Serial.println("\n[IOE] invalid access");
        }
    }
    z80->assertBusReq();
    z80->prepareToReleaseWait();
    z80->blockUntilBusAck();
    z80->releaseWait();
    z80->releaseDataBus();
    z80->releaseBusReq();
}

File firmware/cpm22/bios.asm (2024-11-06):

;
; cp/m 2.2 62K BIOS for sbcz80cpm
;
; written by tkhshmsy@gmail.com
;
                .z80
VERS            .equ    22                      ; CP/M version
BIOSVERS        .equ    01                      ; BIOS version
MSIZE           .equ    62

BIAS            .equ    (MSIZE - 20) * 1024     ; A800h
CCP             .equ    03400h + BIAS            ; DC00h
BDOS            .equ    CCP + 0806h              ; E406h
BIOS            .equ    CCP + 01600h             ; F200h
CPMBOOT         .equ    CCP
WBOOTJUMPER     .equ    0000h
IOBYTE          .equ    0003h
CURRENTDISK     .equ    0004h
BDOSJUMPER      .equ    0005h
FILECTRLBLK     .equ    005ch
DEFAULTDMAADDR  .equ    0080h
TPA_BASE        .equ    0100h

IOE_UARTST      .equ    80h
IOE_UART        .equ    81h
IOE_SELDSK      .equ    82h
IOE_SETTRK      .equ    83h
IOE_SETSEC      .equ    84h
IOE_DSKIO       .equ    85h
IOE_BOOT        .equ    8fh

TRACKOFFSET     .equ    2
MAX_DISKS       .equ    4

LF              .equ    0ah
CR              .equ    0dh

                .org   BIOS
NSECTS          .equ    ($ - CCP)/128
                JP     BOOT
WBOOTENTRY:     JP     WBOOT
                JP     CONST
                JP     CONIN
                JP     CONOUT
                JP     LIST
                JP     PUNCH
                JP     READER
                JP     HOME
                JP     SELDSK
                JP     SETTRK
                JP     SETSEC
                JP     SETDMA
                JP     READ
                JP     WRITE
                JP     LISTST
                JP     SECTRAN
                ; for CP/M 3
                ; JP     CONOST
                ; JP     AUXIST
                ; JP     AUXOST
                ; JP     DEVTBL
                ; JP     MULTIO
                ; JP     FLUSH
                ; JP     MOVE
                ; JP     TIME
                ; JP     SELMEM
                ; JP     SETBNK
                ; JP     XMOVE
                ; JP     USERF
                ; JP     RESERVE1
                ; JP     RESERVE2

; Disk Parameter Header
; for ibm-3740 format
; 4 disks
DPBASE:         .dw     DPTRANS, 0x0000
                .dw     0x0000, 0x0000
                .dw     DIRBUF,DPBLK
                .dw     CSV00, ALV00
                .dw     DPTRANS, 0x0000
                .dw     0x0000, 0x0000
                .dw     DIRBUF, DPBLK
                .dw     CSV01, ALV01
                .dw     DPTRANS, 0x0000
                .dw     0x0000, 0x0000
                .dw     DIRBUF, DPBLK
                .dw     CSV02, ALV02
                .dw     DPTRANS, 0x0000
                .dw     0x0000, 0x0000
                .dw     DIRBUF, DPBLK
                .dw     CSV03, ALV03
; skew table
DPTRANS:	.db	 1,  7, 13, 19	;sectors  1,  2,  3,  4
                .db	25,  5, 11, 17	;sectors  5,  6,  7,  6
                .db	23,  3,  9, 15	;sectors  9, 10, 11, 12
                .db	21,  2,  8, 14	;sectors 13, 14, 15, 16
                .db	20, 26,  6, 12	;sectors 17, 18, 19, 20
                .db	18, 24,  4, 10	;sectors 21, 22, 23, 24
                .db	16, 22		;sectors 25, 26
; disk parameters
DPBLK:  	                        ;disk parameter block, common to all disks
                .dw	26		;sectors per track
                .db	3		;block shift factor
                .db	7		;block mask
                .db	0		;null mask
                .dw	242		;disk size-1
                .dw	63		;directory max
                .db	192		;alloc 0
                .db	0		;alloc 1
                .dw	16		;check size
                .dw	2		;track offset

BOOTMSG:        .db     CR, LF, LF
                .db     MSIZE/10 + "0", MSIZE % 10 + "0"
                .db     "K CP/M ver. "
                .db     VERS/10 + "0", ".", VERS % 10 + "0"
                .db     CR, LF
                .db     "BIOS ver. "
                .db     BIOSVERS/10 + "0", ".", BIOSVERS % 10 + "0"
                .db     " for sbcz80cpm"
                .db     CR, LF, 0

BOOT:
                ; DI
                LD      SP, DEFAULTDMAADDR + 080h
                LD      HL, DMAADDR
                LD      (HL), DEFAULTDMAADDR                
                LD      HL, BOOTMSG
                CALL    CONSTROUT
                XOR     A
                LD      (CURRENTDISK), A
                LD      (PREVDISK), A
                LD      (CUREENTSECTOR), A
                LD      A, 11h
                LD      (IOBYTE), A
WBOOT:
                LD      SP, DEFAULTDMAADDR + 080h
                LD      C, 0
                CALL    SELDSK
                CALL    HOME

                ; DI
                CALL    LOADSYS
GOCPM:
                LD      BC, DEFAULTDMAADDR
                CALL    SETDMA
                LD      A, 0c3h         ; self write
                LD      (WBOOTJUMPER), A
                LD      HL, WBOOTENTRY
                LD      (WBOOTJUMPER + 1), HL
                LD      (BDOSJUMPER), A
                LD      HL, BDOS
                LD      (BDOSJUMPER + 1), HL
                ; EI
                LD      A, (CURRENTDISK)
                LD      C, A
                JP      CPMBOOT

CONSTROUT:                              ; console out string with HL, Break:A,C
                LD      A, (HL)
                CP      00h
                RET     Z
                LD      C, A
                CALL    CONOUT
                INC     HL
                JR      CONSTROUT
CONHEXOUT:                              ; console out hex with C, Break: A,B,C
                LD      A, C
                LD      B, A
                SRA     A
                SRA     A
                SRA     A
                SRA     A
                AND     0fh
                ADD     A, 090H
                DAA
                ADC     A, 040H
                DAA
                LD      C, A
                CALL    CONOUT
                LD      A, B
                AND     0fh
                ADD     A, 090H
                DAA
                ADC     A, 040H
                DAA
                LD      C, A
                CALL    CONOUT
                RET
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

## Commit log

2024-09-12 Add PCB rev.1
    [sbcz80cpm-B_Cu.gbl, sbcz80cpm-B_Mask.gbs, sbcz80cpm-B_Paste.gbp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]
2024-11-07 Add examples/sdcard
    [boot.cfg]
